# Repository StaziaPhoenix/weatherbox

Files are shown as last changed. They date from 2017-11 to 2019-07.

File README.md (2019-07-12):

# Weatherbox
This repository contains code and schematics of the WeatherBox lamp we created for ECE 196 at UC San Diego.
## Contents
* The root directory contains the Arduino code
* The Electrical directory contains Eagle circuit schematics
* The Structural directory contains drawings and Inkscape and SolidWorks schematics

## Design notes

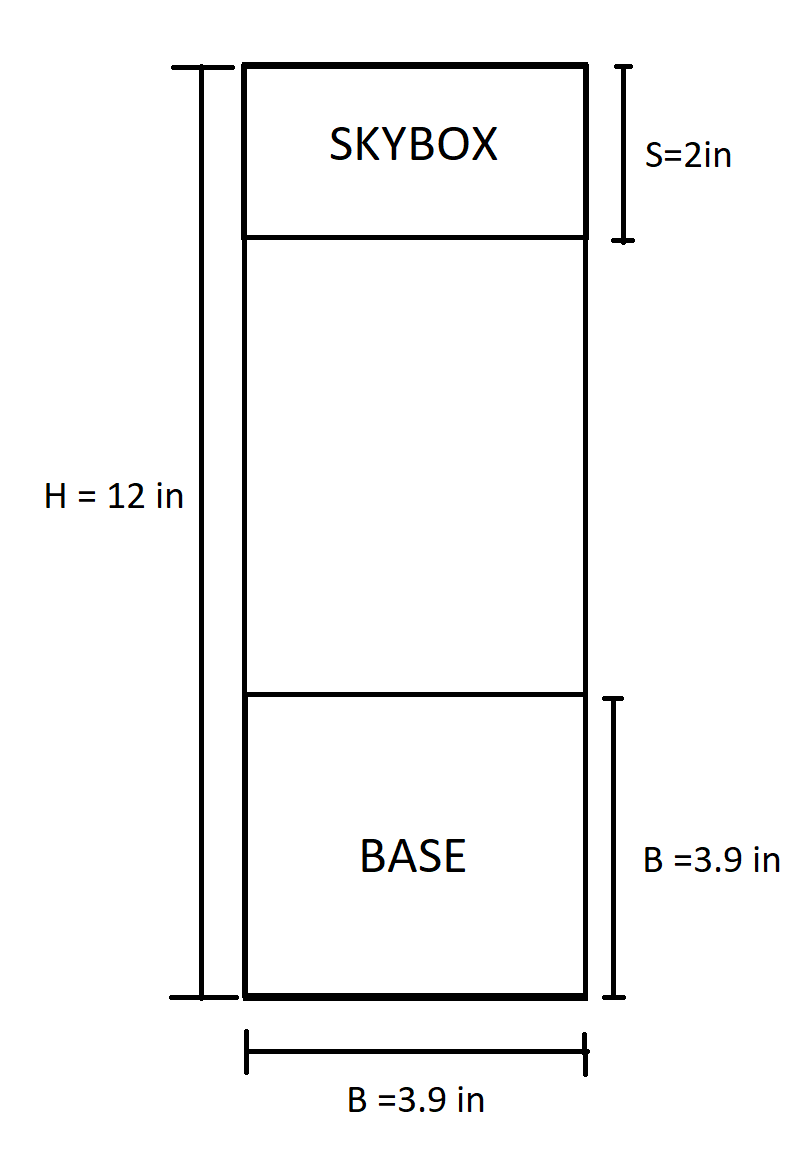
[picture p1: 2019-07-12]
Structural/Untitled.png

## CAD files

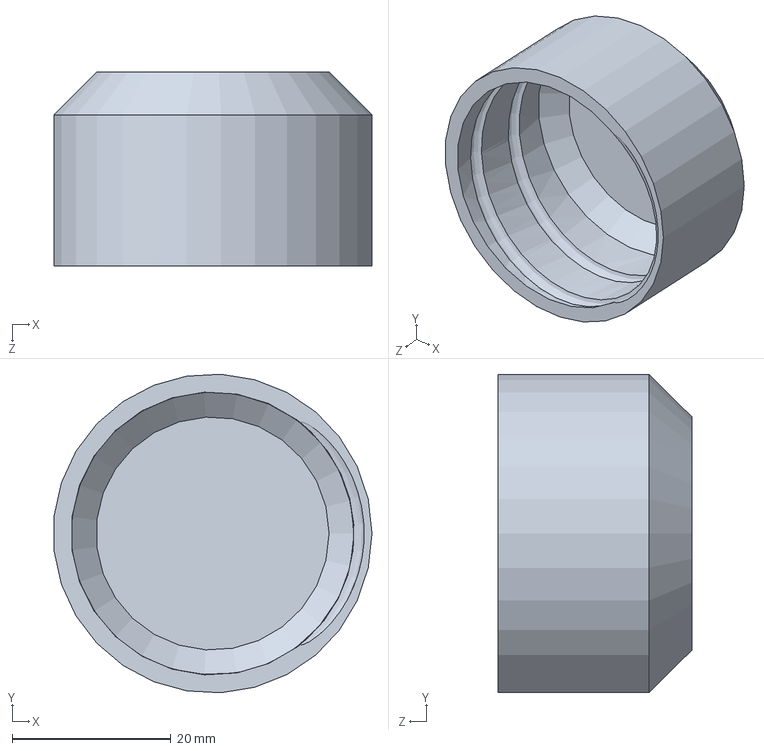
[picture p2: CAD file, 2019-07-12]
Structural/bottlecap.SLDPRT
40.1 x 40.1 x 24.4 mm

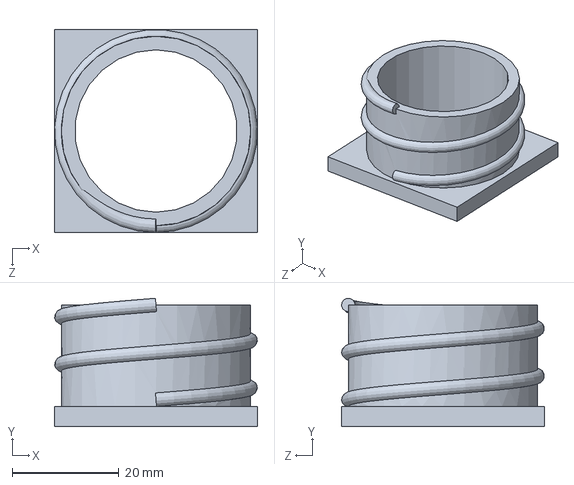
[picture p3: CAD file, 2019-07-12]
Structural/Screw.SLDPRT
38.1 x 24.1 x 38.1 mm

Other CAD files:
Structural/Screw.STL
Structural/bottlecap.STL

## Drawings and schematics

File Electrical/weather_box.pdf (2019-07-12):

# Edited by Alan Yessenbayev, Vladi Iotov, and Linh Nguyen ESP

# Rev. 3.0 Beta

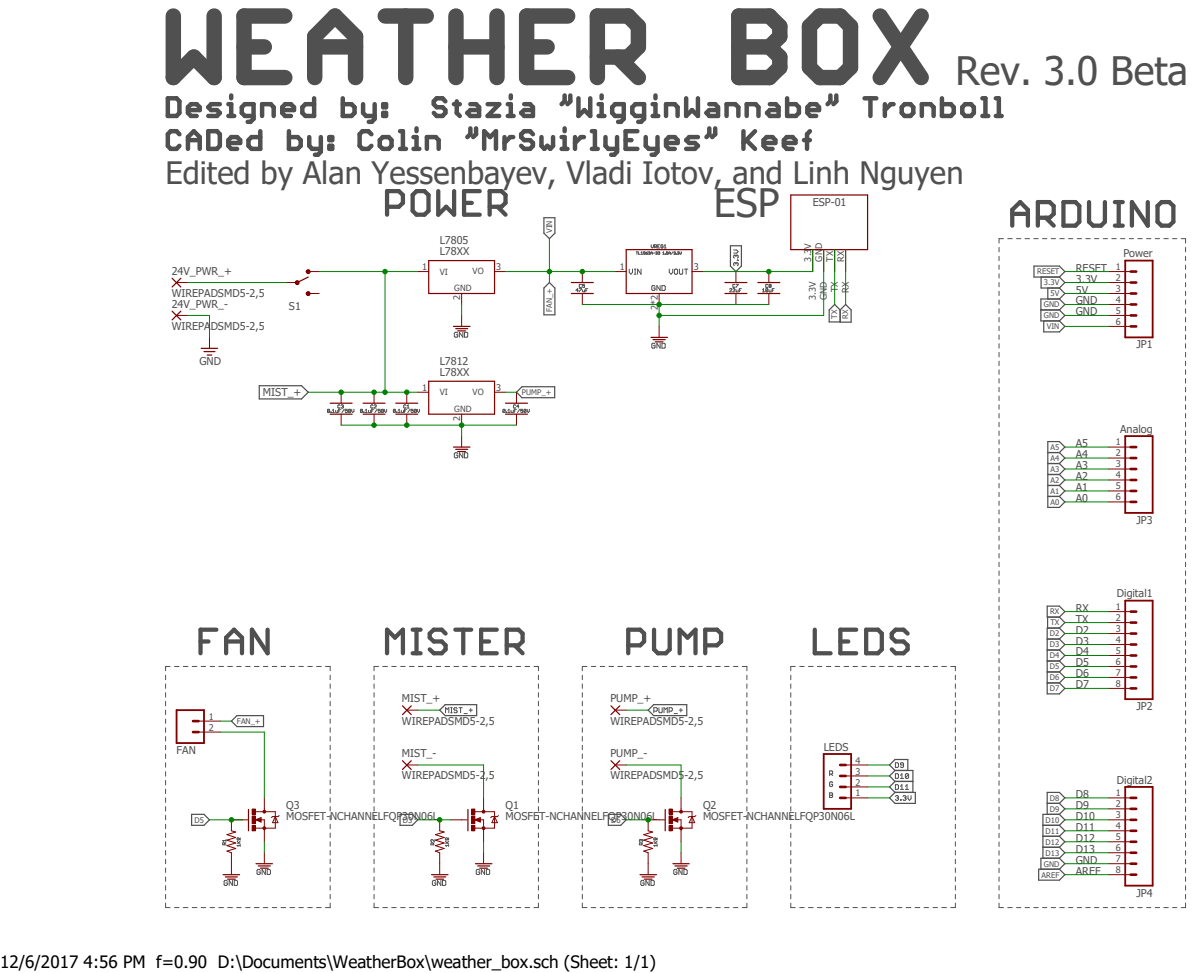
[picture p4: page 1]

12/6/2017 4:56 PM f=0.90 D:\Documents\WeatherBox\weather_box.sch (Sheet: 1/1)

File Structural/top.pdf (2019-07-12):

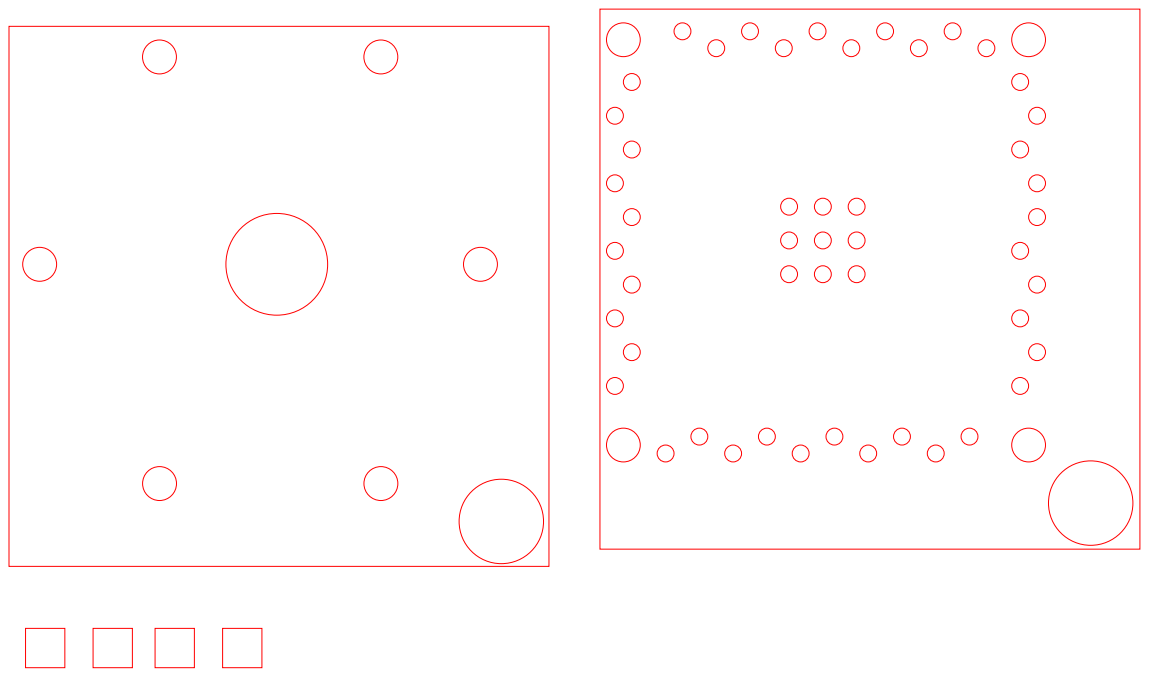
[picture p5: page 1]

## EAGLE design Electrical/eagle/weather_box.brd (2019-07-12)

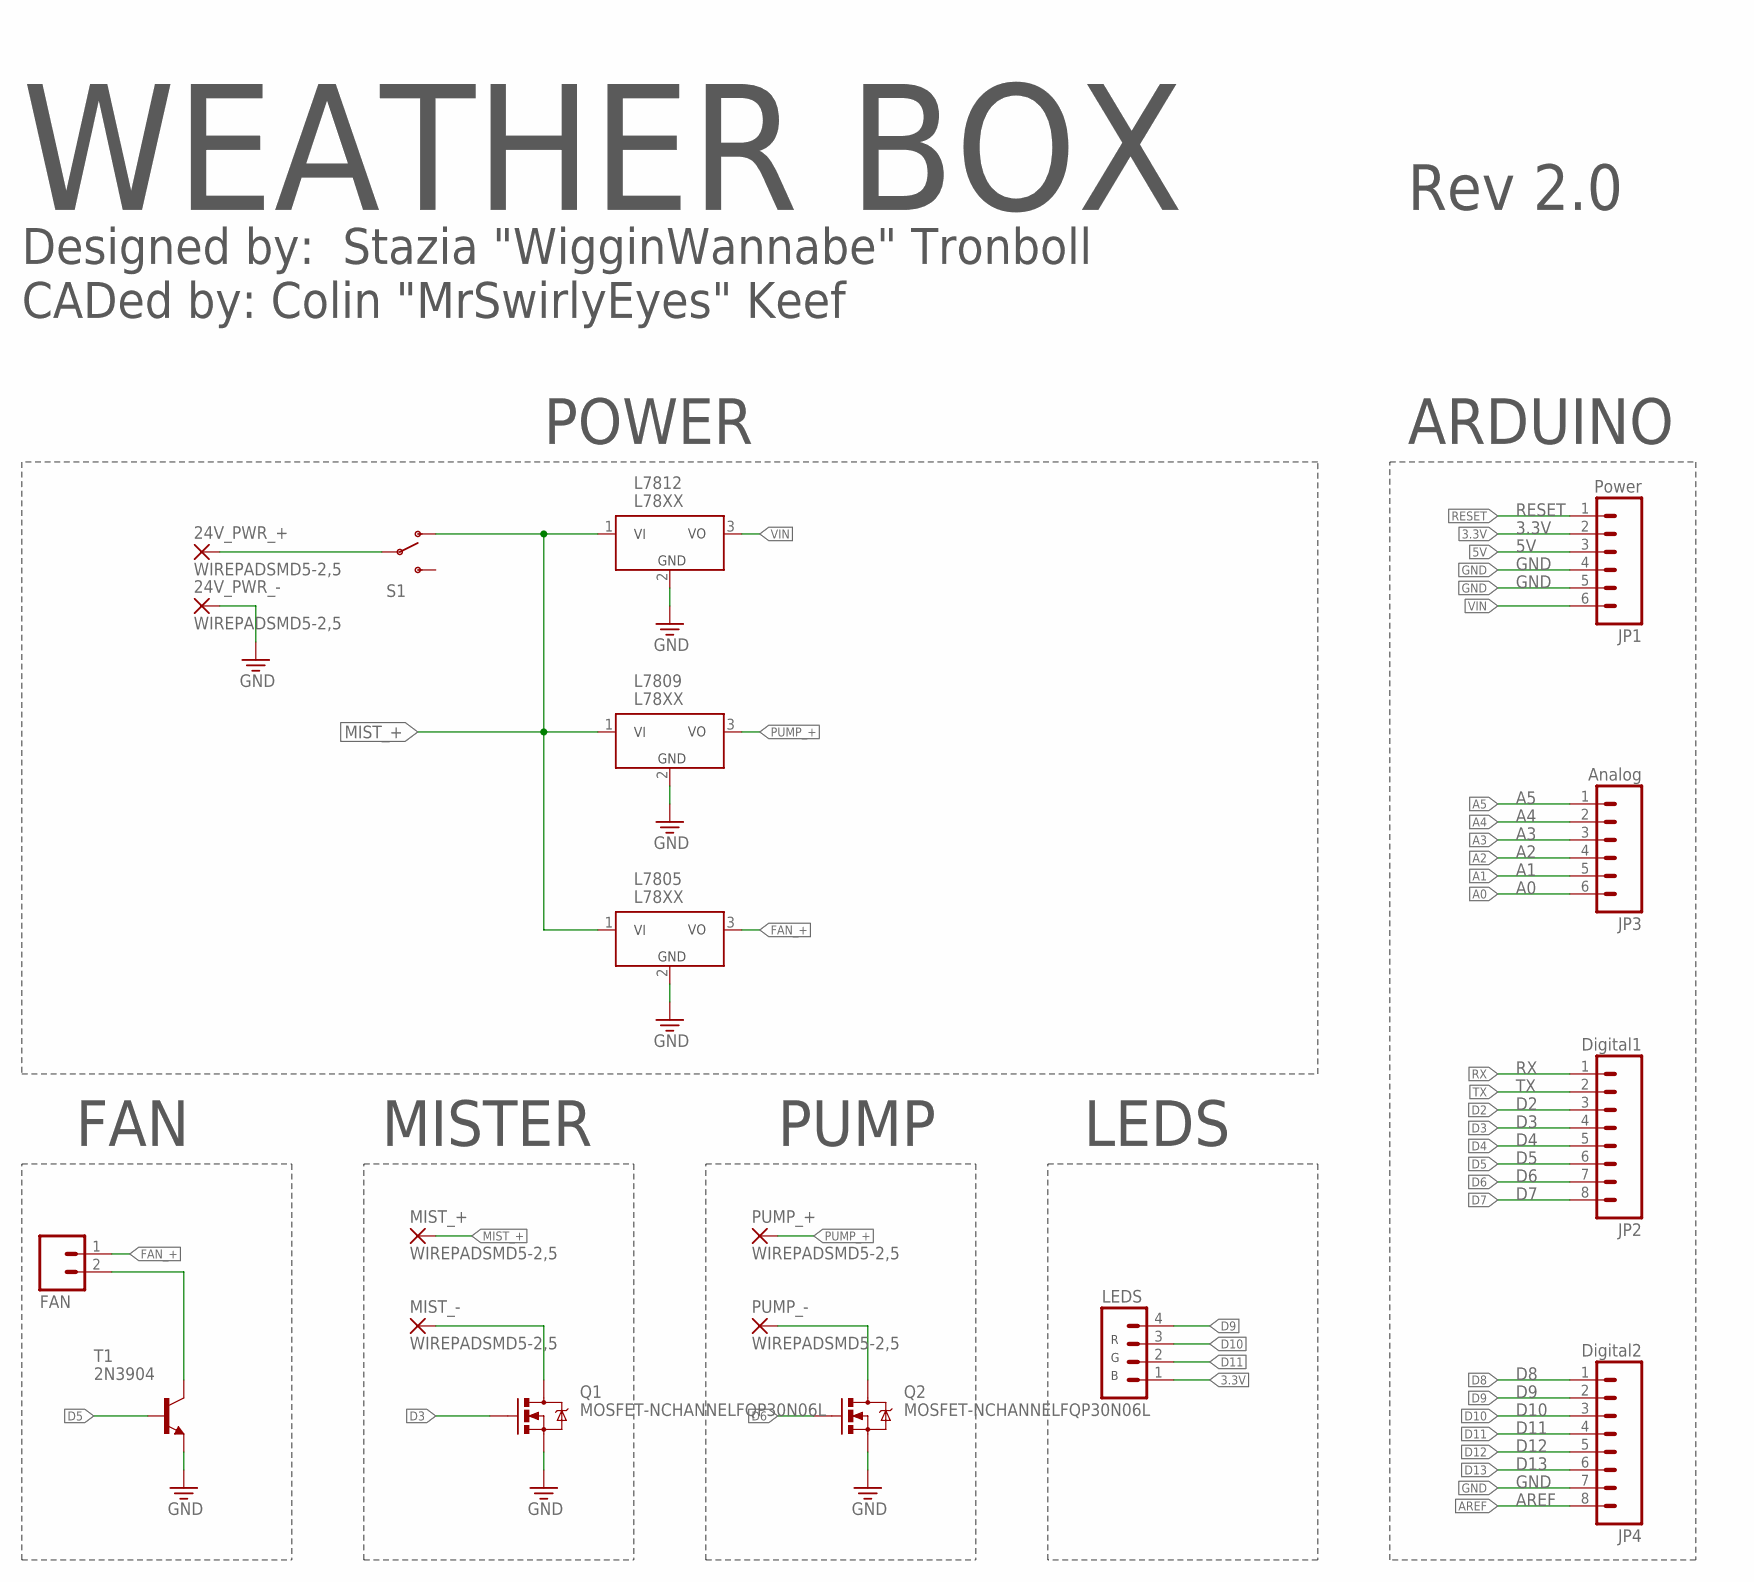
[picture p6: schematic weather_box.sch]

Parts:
24V_PWR_+, 24V_PWR_-: WIREPADSMD5-2,5; 5-2,5
FAN: M02PTH; 1X02
JP1: Power; 1X06
JP2: Digital1; 1X08
JP3: Analog; 1X06
JP4: Digital2; 1X08
L7805, L7809, L7812: L78XX; TO-220-HEATSINK
LEDS: M04PTH; 1X04
MIST_+: WIREPADSMD5-2,5; 5-2,5
MIST_-: WIREPADSMD5-2,5; 5-2,5
PUMP_+: WIREPADSMD5-2,5; 5-2,5
PUMP_-: WIREPADSMD5-2,5; 5-2,5
Q1, Q2: MOSFET-NCHANNELFQP30N06L; TO220V
S1: SWITCH-SPDTPTH; SWITCH-SPDT
T1: 2N3904; TO92

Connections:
3.3V: JP1.2, LEDS.1
5V: JP1.3
A0: JP3.6
A1: JP3.5
A2: JP3.4
A3: JP3.3
A4: JP3.2
A5: JP3.1
AREF: JP4.8
D2: JP2.3
D3: JP2.4, Q1.1 (G)
D4: JP2.5
D5: JP2.6, T1.2 (B)
D6: JP2.7, Q2.1 (G)
D7: JP2.8
D8: JP4.1
D9: JP4.2, LEDS.4
D10: JP4.3, LEDS.3
D11: JP4.4, LEDS.2
D12: JP4.5
D13: JP4.6
FAN_+: FAN.1, L7805.3 (VO)
GND: 24V_PWR_-.1, JP1.4, JP1.5, JP4.7, L7805.2 (GND), L7809.2 (GND), L7812.2 (GND), Q1.3 (S), Q2.3 (S), T1.3 (E)
MIST_+: L7805.1 (VI), L7809.1 (VI), L7812.1 (VI), MIST_+.1, S1.1 (O)
unnamed: 24V_PWR_+.1, S1.2
unnamed: MIST_-.1, Q1.2 (D)
unnamed: FAN.2, T1.1 (C)
unnamed: PUMP_-.1, Q2.2 (D)
PUMP_+: L7809.3 (VO), PUMP_+.1
RESET: JP1.1
RX: JP2.1
TX: JP2.2
VIN: JP1.6, L7812.3 (VO)

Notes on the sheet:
FAN
ARDUINO
MISTER
POWER
PUMP
LEDS
WEATHER BOX
Rev 2.0
Designed by: Stazia "WigginWannabe" Tronboll CADed by: Colin "MrSwirlyEyes" Keef

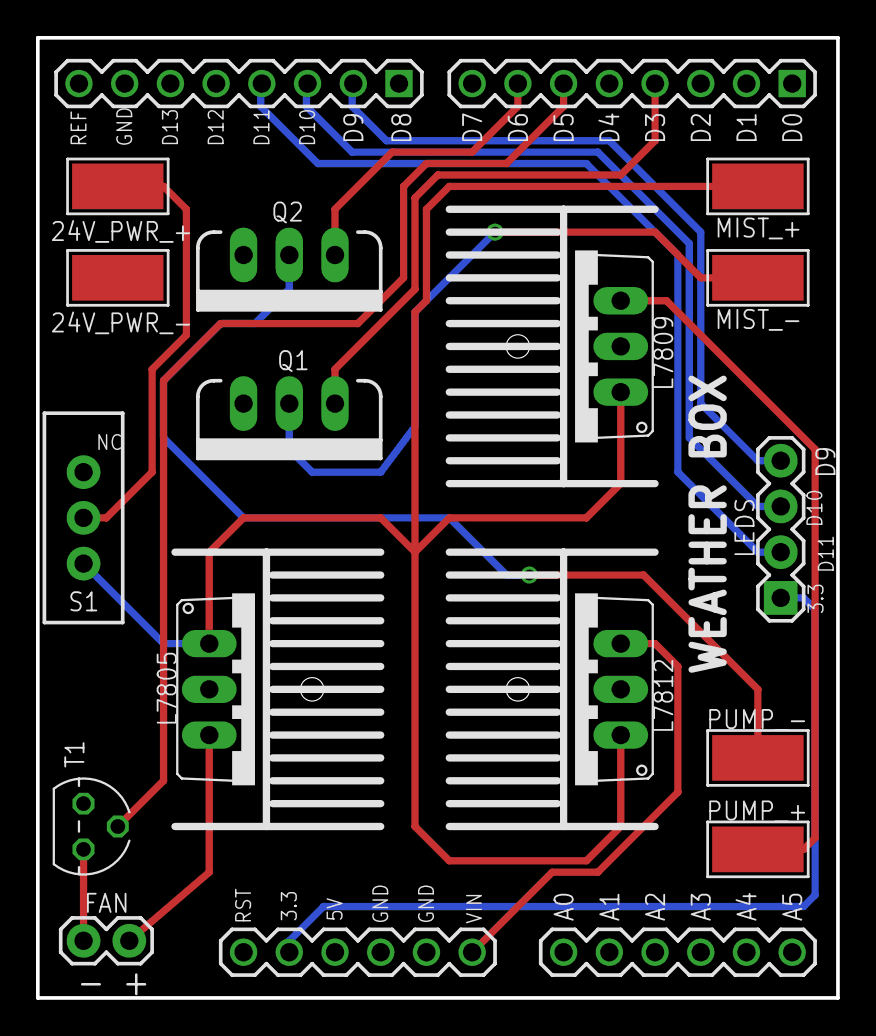
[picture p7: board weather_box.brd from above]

Board: 2 copper layers, 44.5 x 53.3 mm, 19 parts (0 on the bottom side), 16 nets.

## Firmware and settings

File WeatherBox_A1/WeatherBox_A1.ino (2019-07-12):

#include <ArduinoJson.h>
#include "Controller.cpp"
#include "Lights.cpp"

#define sizeOfBuf 512

unsigned int timeoutOver;
unsigned int lastFetch;
unsigned int lastActuation;
#define fetchTime_ms 5000
//unsigned int fetchTime_ms = 5000;//900000; //15 min = 900,000 mSec
#define actuationTime_ms 15000
//unsigned int actuationTime_ms = 15000; //15 sec = 15,000 mSec

short lastWeatherCode;

//Set Up Actuation
Controller controller;
Lights lights;

//Set Up ESP 
char espBuf[sizeOfBuf];  //buffer for new Rx from ESP chip
StaticJsonBuffer<sizeOfBuf> jsonBuffer;


void setup() 
{ 
  pinMode(13, OUTPUT);    //our debug/error pin
  lastWeatherCode = 800;  //clear weather
  
  //Init Serial Port for communication to ESP chip
  Serial.begin(115200);
  
  //Turn off all actuators
  controller.allOff();
  lights.off();

//  for(int i = 0; i < 5; i++)
//        {
//          digitalWrite(13, HIGH);
//          delay(200);
//          digitalWrite(13, LOW);
//          delay(100);
//        }
    //do first case manually
//    doESPStuff(1);
    doESPStuff('$');

  //**Now we can actually begin normal operation**

  //Start System Time
  lastFetch = millis();
  lastActuation = millis();
  delay(1000);
}

void loop() 
{
//  //check if time to actuate current JSON
//  if(millis() - lastActuation >= actuationTime_ms)
//  {
//    setWeather(String(lastWeatherCode));
////    Serial.println("^Used old data");
//    lastActuation = millis();
//  }
//  
//  //check if time to fetch new JSON
//  if(millis() - lastFetch >= fetchTime_ms)
//  {
//    //1 is the command to get the latest JSON
//    //doESPStuff(1);
//    doESPStuff('$');
//    lastFetch = millis();
//  }
  demonstration();
}

void doESPStuff(char _cmd)
//void doESPStuff(int _cmd)
{
    int ret1 = sendESPCmd(_cmd);
    if(!ret1)  //want this to return 0
    {
      
      //Parse JSON & Set Weather
      int ret2 = parseESPJson();
      if(ret2 != 0) //want this to return 0
      {  
        //Error -- could not parse resp -- flash onboard LED depending on error
//        for(int i = 0; i < ret2*4; i++)
//        {
//          digitalWrite(13, HIGH);
//          delay(100);
//          digitalWrite(13, LOW);
//          delay(100);
//        }
      }
      
    }
//    else
//    {
//      //Error -- could not send command -- flash onboard LED 
//      for(int i = 0; i < ret1*3; i++)
//      {
//        digitalWrite(13, HIGH);
//        delay(100);
//        digitalWrite(13, LOW);
//        delay(100);
//      }
//    }
}



//int sendESPCmd(int _cmd)
int sendESPCmd(char _cmd)
{
  int count = 0;
  
  //Reset ESP Rx buffer
  memset(espBuf, 0, sizeOfBuf);
  jsonBuffer.clear();
 
  //cmd 1 = fetch JSON
  Serial.print(_cmd);  //Send ESP chip a command to req from OpenWeatherAPI

  while(!Serial.available())
  {
    
  }
  
//  if(Serial.available())
  if(1)
  {
    do
    {
      while(Serial.available() > 0)
      {  
        espBuf[count] = Serial.read();
//        Serial.print(espBuf[count]);
        timeoutOver = millis()+200; //allow 200mSec before timeout/EOT
        count++;
      }
    }
    while(millis()<timeoutOver);
    //espBuf[count] = '\0'; //Signifies end
    
    Serial.print("\nGot ");
    Serial.print(count);
    Serial.println(" bytes");
    for(int i = 0; i < count; i++)
    {
      if(espBuf[i] == '$')
      {
        Serial.print("!");
      }
      else
      {
        Serial.print(espBuf[i]);
      }
      
    }
    Serial.println("\n");
  }
  else
  {
    Serial.println("Serial not available");
    return 1; 
  }
  return 0; //success
}

int parseESPJson()
{
  JsonObject& root = jsonBuffer.parseObject(espBuf);

  if(!root.success())
  {
    Serial.println("Error 1 in parseESPJson");
    return 1; //error -- JsonObject class could not parse object
  }

  if(root["cod"] == 200)
  {
    //For OpenWeatherAPI, the "cod" internal parameter should be 200 
    JsonObject& weather = root["weather"][0];
    String weatherId = weather["id"];

    if(setWeather(weatherId))
    {
      //success
      return 0;
    }
    else
    {
      Serial.println("Error 2 in parseESPJson");
      return 2; //error 
    }
  }
  else
  {
    Serial.println("Error 3 in parseESPJson");
    return 3; //error -- wrong internal parameter
  }
}


int setWeather(String _wthrID)
{
  int weather = atoi(&_wthrID[0]);
  lastWeatherCode = weather;
  
  if(weather >= 200 && weather < 300)
  {
    //thunderstorm
    storm(10);
  }
  else if(weather >= 300 && weather < 400)
  {
    //drizzle (lumped in with "light rain")
    rain();
  }
  else if(weather >= 500 && weather < 600)
  {
    //rain
    rain();
  }
  else if(weather >= 700 && weather < 800)
  {
    //atmospheric conditions
    if(weather == 701 || weather == 721)
    {
      lowFog();
    }
    else if(weather == 741 || weather == 781)
    {
      highFog();
    }
    
  }
  else if(weather > 800 && weather < 900)
  {
    //clouds
    lowFog();
  }
  else if(weather >= 900 && weather < 1000)
  {
    //extreme weather
    storm(10);
  }
  else if(weather == 800)
  {
      //clear
      sunrise();
  }
  else
  {
    //unknown weather ID -- error
    return 0;
  }
  
  Serial.print("Successfully set weather to: ");
  Serial.println(weather);
  return 1; //success
}









/* SUNRISE */
void sunrise() {
  highFog();
  delay(5000);
  controller.allOff();
  delay(100);
  lights.sunrise();
}

/* STORM */
void storm(int seconds) {
  lights.set(0,0,30);
  rain();

  lowFog();
  delay(2000);
  
  for (int i = 0; i < seconds-1; i++) {

    if (i % 2 == 1) {
      lowFog();
    } else {
      highFog();
    }
    lights.flash(255,255,255);
    delay(900);
  }

}

/* RAIN */
void rain() {
  controller.pumpOn();
}

void rain(int redV, int greenV, int blueV) {
  controller.pumpOn();
  lights.on(redV, greenV, blueV);
}


/* LOW FOG */
void lowFog(int _time, int redV, int greenV, int blueV) {
  controller.misterOn();
  lights.on(redV, greenV, blueV);

  for (int i = 0; i < _time/200; i = i + 200) {
    controller.fanOn();
    delay(200);
    controller.fanOff();
  }
  
}

void lowFog() {
  controller.misterOn();
  controller.fanOn();
  delay(200);
  controller.fanOff();
}

void lowFog(int redV, int greenV, int blueV) {
  controller.misterOn();
  lights.on(redV, greenV, blueV);
}


/* HIGH FOG */
void highFog() {
  controller.misterOn();
  controller.fanOn();
}

void highFog(int redV, int greenV, int blueV) {
  controller.misterOn();
  controller.fanOn();
  lights.on(redV, greenV, blueV);
}

void demonstration() {

  // Lights
//  byte rate = 50;
//  lights.fadeInto(255,0,0,rate); // red
////  lights.fadeInto(255,140,0,rate); // orange
////  lights.fadeInto(255,255,0,rate); // yellow
//  lights.fadeInto(0,255,0,rate); // green
//  lights.fadeInto(0,0,255,rate); // blue
////  lights.fadeInto(75,0,130,rate); // indigo
////  lights.fadeInto(238,130,238,rate); // violet
////  lights.fadeInto(199,21,133,rate); // pink
//
//  lights.set(255,0,0); // red
//  delay(rate);
//  lights.set(255,140,0); // orange
//  delay(rate);
//  lights.set(255,255,0); // yellow
//  delay(rate);
//  lights.set(0,255,0); // green
//  delay(rate);
//  lights.set(0,0,255); // blue
//  delay(rate);
//  lights.set(75,0,130); // indigo
//  delay(rate);
//  lights.set(238,130,238); // violet
//  delay(rate);
//  lights.set(199,21,133); // pink
//  delay(rate);

//  lights.off();
  delay(1000);
  
  // Mister
  lowFog(5000, 255, 255, 255);

  // Mister and Fan
  highFog(255, 255, 255);
  delay(3000);

  controller.allOff();
  delay(10);
  
  // Pump
  rain();
  delay(5000);

  storm(10);

  lights.fadeInto(255,255,255,500);
}

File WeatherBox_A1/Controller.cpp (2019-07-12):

#include "Arduino.h"

#define pump 6
#define mister 3
#define fan 5

class Controller {
  private:


  public:

    Controller () {}
  
    void pumpOn() {
      analogWrite(pump, 255);
    }
    
    void pumpOff() {
      analogWrite(pump, 0);
    }
    
    void misterOn() {
      analogWrite(mister, 255);
    }
    
    void misterOff() {
      analogWrite(mister, 0);
    }
    
    void fanOn() {
      analogWrite(fan, 255);
    }
    
    void fanOff() {
       analogWrite(fan, 0);
    }

    void allOn() {
      pumpOn();
      misterOn();
      fanOn();
    }

    void allOff() {
      pumpOff();
      misterOff();
      fanOff();
    }

    void clearDisplay(int seconds) {
      allOff();
      fanOn();
      delay(seconds*1000);
      fanOff();
    }
};

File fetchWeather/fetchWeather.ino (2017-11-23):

#include <Arduino.h>
#include <ESP8266WiFi.h>
#include "Timer.h"
#include <ESP8266WiFiMulti.h>

ESP8266WiFiMulti wifiMulti;

#define HTTP_QUERY_SIZE 1400

// TODO: Edit wifi connection info
const char* ssid = "UCSD-GUEST";
const char* pw = "";

uint8_t httpQuery[HTTP_QUERY_SIZE];

static WiFiClient client;

char *server = "api.openweathermap.org";
char *apiKey = "5d7171bef3c4d2055fcff9885bb2cf66";
char *cityNames[] = {"San Diego, US"};
char *currentWeather = "GET /data/2.5/weather?";


uint16_t queryLength = 0;
bool isRunning = false;
String httpResponse = "";
int numberOfCity = 1;

void setup() {
  // put your setup code here, to run once:  
  Serial.begin(115200);
  while (!Serial);// wait for serial port to connect.
  Serial.println();

  // Connect to Wifi network
  WiFi.begin(ssid,pw);


  // Print the network that the chip is connected to
  Serial.println(WiFi.localIP());

  numberOfCity = sizeof(cityNames) / sizeof(char*);
  
}

void loop() {  
  // while there's is a request from arduino, fetch
  /*
  while (Serial.read() == 1) {
    apiLoop();
    httpLoop();
  }
  */
  apiLoop();
  httpLoop();
  delay(10000);
}

void apiLoop()
{

  static int index = 0;

  queryLength = getQueryCurrentWeather(httpQuery, cityNames[index++],
      apiKey);
  if(index >= numberOfCity) {
    index = 0;
  }
    
  httpResponse = "";
  
  // Use object of WiFiClient WiFiClient class to create TCP connections
  if(client.connect(server, 80))
  {
    isRunning = true;
    client.print((char *) httpQuery);
  
  }
}

char buf[1024];
uint8_t buf_int = (uint8_t)atoi(buf);

String f = "\r\n\r\n";
void httpLoop()
{
  if(isRunning)  
  {
    // Count the amount of data availble for reading
    uint16_t cnt = client.available();

    if(cnt > 0)
    {
      // If the number of bytes to be read is greater than 128, just
      // ready 128 bytes. Otherwise, fill the bytes.
      //
      uint8_t tryRead = cnt > 128 ? 128 : cnt;
      memset(buf, 0, 1024);

      // Store read bytes in recv
      //uint16_t recv = WiFiClient.read(buf_int, tryRead);
      String recv = client.readStringUntil('\r');
      httpResponse = httpResponse + buf;      

      Serial.println("Received");
      Serial.println(recv);
      //Save index of last occurence of the string f
      int idx = httpResponse.lastIndexOf(f);
      if(idx >= 0)
        httpResponse = httpResponse.substring(idx + 4);
    }
    
    if(!client.connected())
    {
      isRunning = false;
      Serial.println("Client not connected");
      
    }
  }
}

uint16_t writeString(const char* string, uint8_t* buf, uint16_t pos) 
{
    const char* idp = string;
    uint16_t i = 0;
 
    while (*idp) 
    {
        buf[pos++] = *idp++;
        i++;
    }
    
    return pos;
}

uint16_t getQueryCurrentWeather(uint8_t* query, char* cityName, 
    char* apiKey)

{
  uint16_t queryLength = 0;

  queryLength = writeString(currentWeather, query, queryLength);
  queryLength = writeString("q=", query, queryLength);
  queryLength = writeString(cityName, query, queryLength);
  queryLength = writeString("&units=metric&appid=", httpQuery, queryLength);
  queryLength = writeString(apiKey, query, queryLength);  

  queryLength = writeString(
      " HTTP/1.1\r\nHost: api.openweathermap.org\r\n", query, queryLength);
  queryLength = writeString(
      "Connection: Closed\r\n\r\n", query, queryLength);
  
  return queryLength;
}

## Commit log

2017-11-21 Make esp chip a slave, listening for a 1 (request) from the Rx pin and fetch data at request
2017-11-21 remove gpio pin
2017-11-30 Nov 29 Working Arduino Code
2018-07-16 Added Electrical and Structural Schematics
    [Screw.SLDPRT, Screw.STL, bottlecap.SLDPRT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]

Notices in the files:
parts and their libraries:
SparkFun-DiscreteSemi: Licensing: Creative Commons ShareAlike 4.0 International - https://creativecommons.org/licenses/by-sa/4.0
